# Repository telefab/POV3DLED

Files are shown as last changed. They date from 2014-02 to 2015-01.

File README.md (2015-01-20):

POV3DLED - Rotating LED globe
========

* The "Globe" directory contains an Arduino library to control the globe.
Examples are also provided. Code is also provided to manage a communication
between the globe and an external Arduino, by modulating the ground wire that
powers the globe logic.

* The "Things" directory contains 3D models of parts of the globe.

* The "ImageConverter" directory contains a Java program to convert
images to be able to draw them on the globe.

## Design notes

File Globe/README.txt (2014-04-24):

This is a library to control a LED globe using low-level functions. It also defines a bus that can be used to communicate with the globe using its ground wire.

Examples are available to display the world, to display a runner trying to go faster than the globe, or to display text.

For bus communication, an example is available where the text and the color can be changed.

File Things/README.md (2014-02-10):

Things
=========

This directory contains 3D models. OpenSCAD is required to open scad files.

The models are:

* connection-base: the LED and light sensor to detect a reference angle.

* jack2stick: the connection between the jack (rotating contact) and the globe axis.

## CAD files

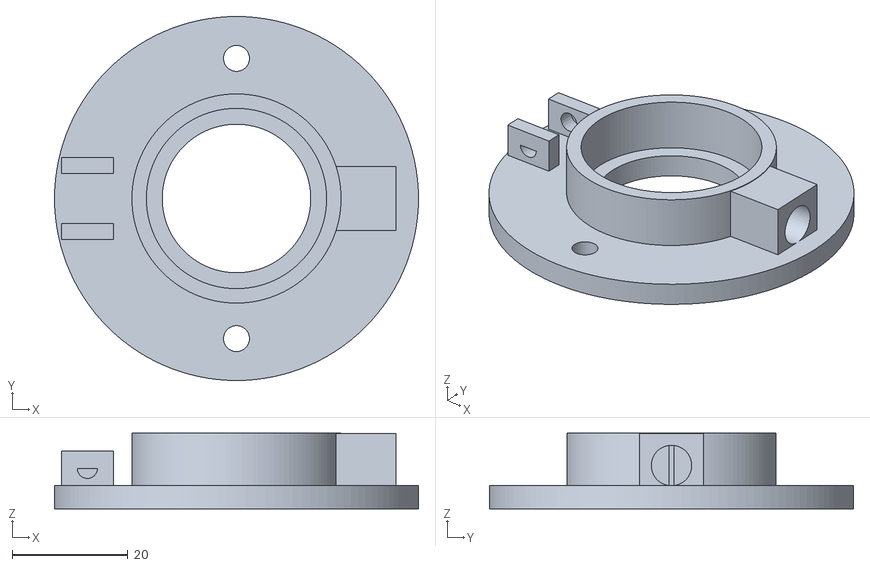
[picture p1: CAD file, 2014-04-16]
Things/base.stl
63.0 x 63.0 x 13.1

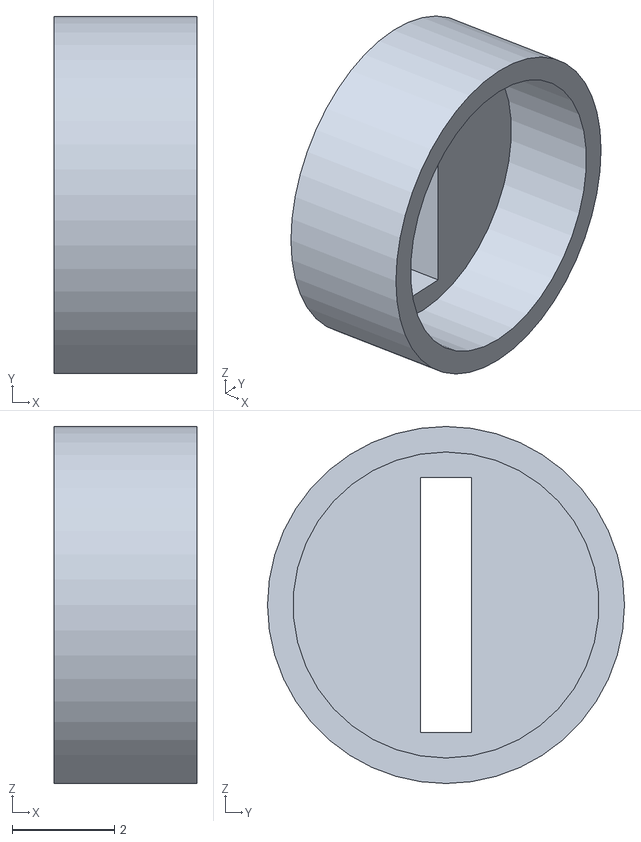
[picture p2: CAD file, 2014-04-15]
ThingsNew/led-cache.stl
2.80 x 7.00 x 7.00

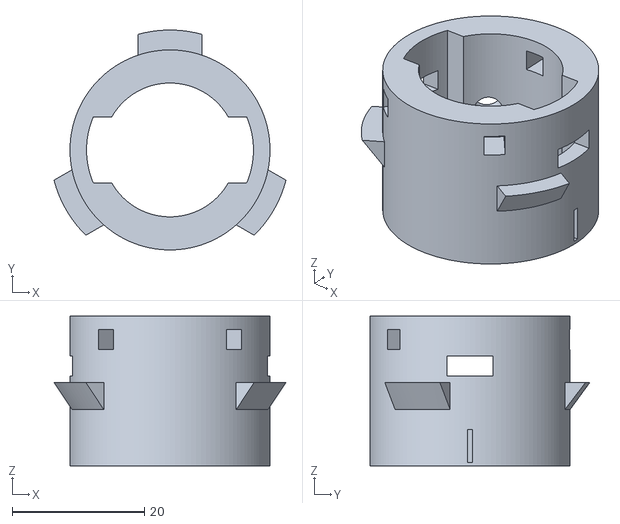
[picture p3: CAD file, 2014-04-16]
Things/cylinder.stl
35.0 x 33.2 x 22.6

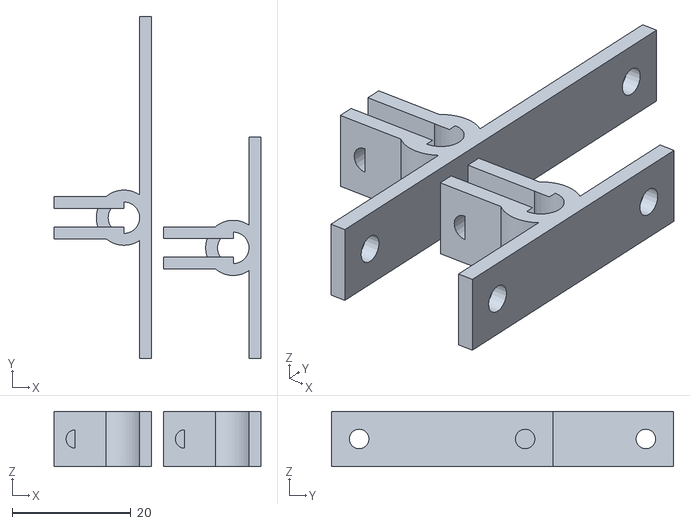
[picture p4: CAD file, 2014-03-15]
Things/arduino-holder.stl
34.8 x 57.6 x 9.30

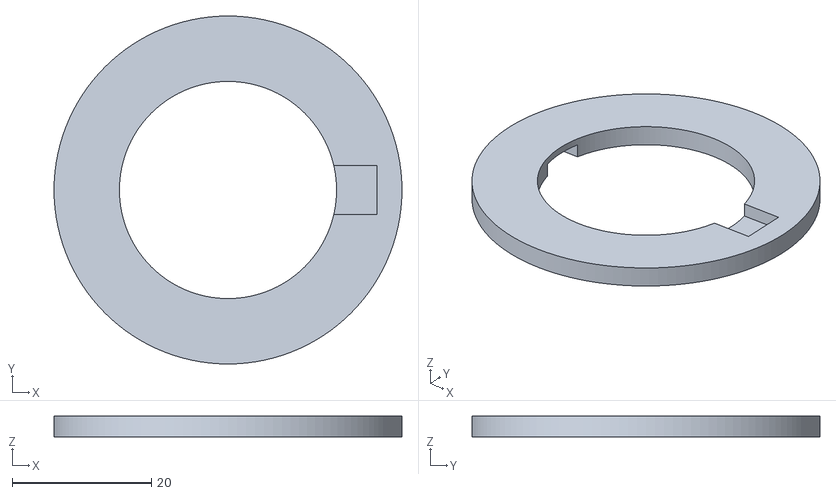
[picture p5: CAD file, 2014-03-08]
Things/spacer.stl
50.0 x 50.0 x 3.00

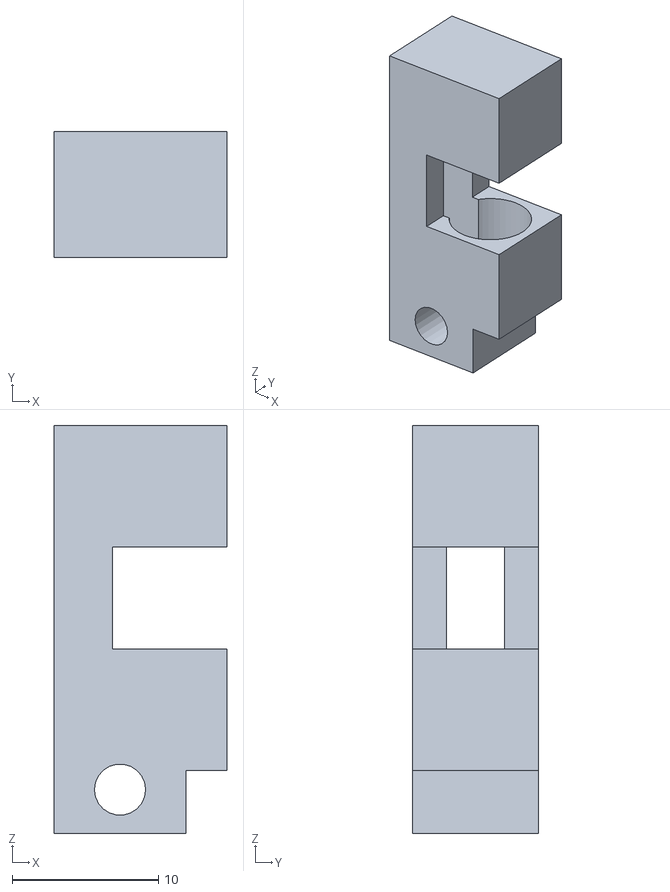
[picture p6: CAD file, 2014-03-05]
Things/connector.stl
11.8 x 8.60 x 27.9

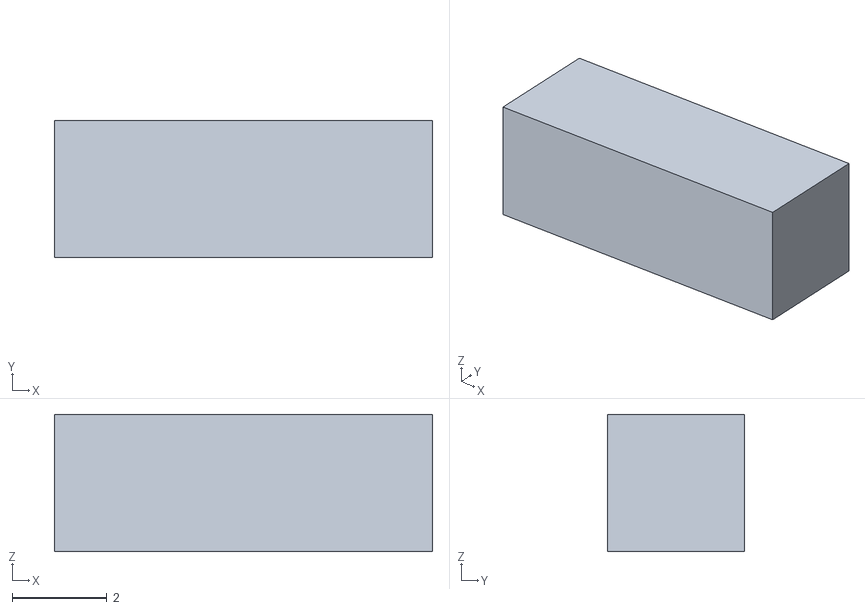
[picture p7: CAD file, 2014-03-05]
Things/block.stl
8.00 x 2.90 x 2.90

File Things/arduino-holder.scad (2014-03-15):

// Arduino support

// Resolution
$fa = 3; // Minimum angle (lower = higher max resolution, def 12)
$fs = 0.5; // Max fragment size (lower = higher min resolution, def 2)

// Measured parameters
holder_diam = 5.3;
hole_diam = 3.3;
dist_small = 27.94;
dist_large = 48.26;
screw_diam = 3.1;
center_offset = 5.08;

// Support parameters
depth = 2;
hole_space = 3;
screw_space = 2;
hole_size = (holder_diam + depth*2) / 3;

// Generic support
module support(dist, offset) {
	difference() {
		union() {
			// Base
			cube([hole_diam + hole_space * 2, dist + hole_diam + hole_space * 2, depth]);
			// Holder holder
			translate([0, dist/2 + hole_diam/2 + hole_space + offset, holder_diam/2 + depth])
				rotate([0, 90, 0])
					cylinder(r = holder_diam/2 + depth, h = hole_diam + hole_space * 2);
			// Holder screw support
			translate([0, dist/2 + hole_diam/2 + hole_space + offset - (hole_size + depth*2)/2, holder_diam/2 + depth])
				cube([hole_diam + hole_space * 2, hole_size + depth * 2, holder_diam/2 + depth + screw_diam + screw_space*2]);
		}
		// Holder space
		translate([0, dist/2 + hole_diam/2 + hole_space + offset, holder_diam/2 + depth])
			rotate([0, 90, 0])
				cylinder(r = holder_diam/2, h = hole_diam + hole_space * 2);
		// Holder screw support hole
		translate([0, dist/2 + hole_diam/2 + hole_space + offset - (hole_size + depth*2)/2 + depth, holder_diam/2 + depth])
			cube([hole_diam + hole_space * 2, hole_size, holder_diam/2 + depth + screw_diam + screw_space*2]);	
		// Holder screw space
		translate([hole_diam/2 + hole_space, dist/2 + hole_diam/2 + hole_space + offset - (hole_size + depth*2)/2, 2* depth + holder_diam + screw_space + screw_diam / 2])
			rotate([-90, 0, 0])
				cylinder(r = screw_diam/2, h = hole_size + depth * 2);
		// Arduino connection holes 
		translate([hole_space + hole_diam/2, hole_space + hole_diam/2, 0])
			cylinder(r = hole_diam/2, h = depth);
		translate([hole_space + hole_diam/2, hole_space + hole_diam/2 + dist, 0])
			cylinder(r = hole_diam/2, h = depth);
	}
}

// Small support
rotate([0, -90, 0]) 
	support(dist_small, 0);
// Big support
translate([-holder_diam - screw_diam - screw_space * 2 - depth*3, 0, 0])
	rotate([0, -90, 0]) 
		support(dist_large, -center_offset);

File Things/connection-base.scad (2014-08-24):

// Connection base
// This file contains separate elements:
// * a static base, fixed to the motor;
// * a rotating cylinder, fixed to the sphere.
// * a connector 
// It is used to transmit power between the base and the cylinder,
// and to add a LED and light sensor to detect a reference angle.

// Resolution
$fa = 3; // Minimum angle (lower = higher max resolution, def 12)
$fs = 0.5; // Max fragment size (lower = higher min resolution, def 2)

// Wire
wire_diam = 1.8;
// Motor base
base_diam = 63;
base_height = 4.0;
// Base screw
base_screw_diam = 4.5;
base_screw_sep = 48.5;
// Base hole
base_hole_height = base_height;
base_hole_diam = 25.7;
// Rotating cylinder
cyl_offset = base_height + 1;
cyl_in_diam = 20.2;
cyl_width = 2.5;
cyl_wire_width = 2.5;
cyl_wire_space = 10;
// Rotating screw
cyl_screw_offset = 13.3;
cyl_screw_diam = 4.1;
// light sensor
sensor_offset = 0.5;
sensor_diam = 5;
sensor_opening_width = 0.8;
// LED box
led_length = 12;
led_diam = 7;
led_box_width = 2;
led_opening_width = sensor_opening_width;
// LED cache
cache_width = 2.5;
cache_height = cyl_screw_offset - 0.2;
cache_diam = cyl_in_diam + (cyl_width + cyl_wire_width)*2 + 1;
// Conductor
conductor_diam_in = 31;
conductor_diam_out = 50;
conductor_height = 1;
conductor_sup_height = cyl_screw_diam;
conductor_sup_width = 10;
conductor_space = 3;
conductor_wire_space = 7;
conductor_wire_sep = 1;
conductor_offset = cyl_screw_offset + cyl_screw_diam + 0.2;
conductor_block_width = 3;
// Connector
connector_sup_offset = 1.3;
connector_sup_width = 4;
connector_base_depth = 2.8;
connector_base_width = 9;
connector_base_height = 6;
connector_base_hole_diam = 3.5;
connector_contact_diam = 7;
connector_contact_height = 7.5;
connector_contact_sep = 1;
connector_contact_wall = 0.8;
connector_sup_length = connector_contact_diam + connector_contact_wall*2;
connector_wire_space = 4;
// Cylinder height
cyl_height = conductor_offset + conductor_height * 2 + conductor_space + conductor_block_width + 2 - cyl_offset;

// Non-moving part
module base() {
	difference() {
		union() {
			difference() {
				union() {
					difference() {
						// Base
						cylinder(h = base_height, r = base_diam/2);
						// Bottom hole
						cylinder(h = base_hole_height, r = base_hole_diam/2);
						
					}
					// LED circular cache
					difference() {
						// Cylinder
						cylinder(h = cache_height, r = cache_diam/2 + cache_width);
						// Inside diameter
						cylinder(h = cyl_height, r = cache_diam/2);
					}
					// LED box
					translate([cache_diam/2, - led_diam/2 - led_box_width, 0]) {
						cube([led_length, led_diam + 2 * led_box_width, led_diam + led_box_width + base_height]);
					}
				}
				// LED space
				translate([cache_diam/2, 0, led_diam/2 + base_height])
					rotate([0, 90, 0])
						cylinder(h = led_length+1, r = led_diam/2);
				translate([cache_diam/2 - 2, -led_opening_width/2, base_height])
					cube([cache_width+4, led_opening_width, led_diam]);
			}
			// Holding part for the connector
			difference() {
				translate([-conductor_diam_out/2 - connector_sup_width - connector_sup_offset, -connector_sup_length/2 - connector_base_depth, 0])
					cube([connector_base_width, connector_sup_length + connector_base_depth*2, connector_base_height + base_height]);
				translate([-conductor_diam_out/2 - connector_sup_width - connector_sup_offset, -connector_sup_length/2, 0])
					cube([connector_base_width, connector_sup_length, connector_base_height + base_height]);
				translate([-conductor_diam_out/2 - connector_sup_offset - connector_sup_width + connector_base_width/2, connector_sup_length/2 + connector_base_depth, base_height + connector_base_height/2])
					rotate([90, 0, 0])
						cylinder(h = connector_sup_length + connector_base_depth*2, r = connector_base_hole_diam/2);
			}
		}
		// Screws
		translate([0,base_screw_sep/2,0])
			cylinder(h = cache_height, r = base_screw_diam/2);
		translate([0,-base_screw_sep/2,0])
			cylinder(h = cache_height, r = base_screw_diam/2);
	}
}

// Rotating part
module cyl() {
	translate([0, 0, cyl_offset]) {
		union() {
			difference() {
				// Cylinder
				cylinder(h = cyl_height, r = cyl_in_diam/2 + cyl_width + cyl_wire_width);
				// Inside diameter
				cylinder(h = cyl_height, r = cyl_in_diam/2);
				// Wire space
				intersection() {
					cylinder(h = cyl_height, r = cyl_in_diam/2 + cyl_wire_width);
					translate([-cyl_in_diam/2-(cyl_width+cyl_wire_width), -cyl_wire_space/2, 0])
						cube([cyl_in_diam+2*(cyl_width+cyl_wire_width), cyl_wire_space, cyl_height]);
				}
				// Screw
				translate([0, 0, cyl_screw_offset + cyl_screw_diam/2 - cyl_offset])
					rotate([0, 90, 130])
						cylinder(h = cyl_in_diam/2+cyl_width+cyl_wire_width, r = cyl_screw_diam/2);
				// Light sensor
				translate([cyl_in_diam/2 + cyl_wire_width - 1, 0, sensor_offset + sensor_diam/2])
					rotate([0, 90, 0])
						cylinder(h = cyl_width, r=sensor_diam/2);
				translate([cyl_in_diam/2 + cyl_wire_width - 1, -sensor_opening_width/2, sensor_offset])
					cube([cyl_width+4, sensor_opening_width, sensor_diam]);
				// Holes to connect the conductors
				translate([-cyl_in_diam/2-(cyl_width+cyl_wire_width), -conductor_wire_space/2, conductor_offset - cyl_offset + conductor_height])
					cube([cyl_in_diam+2*(cyl_width+cyl_wire_width), conductor_wire_space, conductor_space]);
				// Holes to block the top conductor
				rotate([0,0,50])
					translate([-cyl_in_diam/2-(cyl_width+cyl_wire_width), -conductor_block_width/2, conductor_offset - cyl_offset + 2*conductor_height + conductor_space])
						cube([cyl_in_diam/2+(cyl_width+cyl_wire_width), conductor_block_width, conductor_block_width]);
				rotate([0,0,130])
					translate([-cyl_in_diam/2-(cyl_width+cyl_wire_width), -conductor_block_width/2, conductor_offset - cyl_offset + 2*conductor_height + conductor_space])
						cube([cyl_in_diam/2+(cyl_width+cyl_wire_width), conductor_block_width, conductor_block_width]);
				rotate([0,0,270])
					translate([-cyl_in_diam/2-(cyl_width+cyl_wire_width), -conductor_block_width/2, conductor_offset - cyl_offset + 2*conductor_height + conductor_space])
						cube([cyl_in_diam/2+(cyl_width+cyl_wire_width), conductor_block_width, conductor_block_width]);
				
			}
			// Conductor support
			intersection() {
				translate([0, 0, conductor_offset - cyl_offset - conductor_sup_height]) {
					difference() {
						cylinder(h = conductor_sup_height, r1 = cyl_in_diam/2 + cyl_width + cyl_wire_width, r2 = cache_diam/2 + cache_width);
						cylinder(h = conductor_sup_height, r1 = cyl_in_diam/2 + cyl_wire_width, r2 = cyl_in_diam/2 + cyl_width + cyl_wire_width);
					}
				}
				union() {
					rotate([0, 0, 0])
						translate([-conductor_sup_width/2+0.2, 0, 0])
							cube([conductor_sup_width-0.4, cyl_in_diam + 2*(cyl_width + cyl_wire_width), conductor_offset - cyl_offset]);
					rotate([0, 0, 120])
						translate([-conductor_sup_width/2+0.2, 0, 0])
							cube([conductor_sup_width-0.4, cyl_in_diam + 2*(cyl_width + cyl_wire_width), conductor_offset - cyl_offset]);
					rotate([0, 0, 240])
						translate([-conductor_sup_width/2+0.2, 0, 0])
							cube([conductor_sup_width-0.4, cyl_in_diam + 2*(cyl_width + cyl_wire_width), conductor_offset - cyl_offset]);
				}
			}
		}
	}
}
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

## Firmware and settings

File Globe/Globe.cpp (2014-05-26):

#if defined(__AVR_ATmega2560__)

#include "Globe.h"
#include <avr/interrupt.h>

#define START_TIMER3 TCCR3B |= (1 << WGM12) | (1 << CS10)
#define STOP_TIMER3 TCCR3B &= ~((1 << WGM12) | (1 << CS10))

Globe* Globe::singleton = 0;

const PIN_TYPE Globe::ledPins[GLOBE_LEDS] = {PIN_F(2), PIN_F(3), PIN_F(4), PIN_F(5), PIN_F(6), PIN_F(7), PIN_K(0), PIN_K(1), PIN_K(2), PIN_B(1), PIN_B(0),
  PIN_B(3), PIN_B(2), PIN_L(1), PIN_K(3), PIN_L(3), PIN_L(2), PIN_L(5), PIN_L(4), PIN_L(7), PIN_L(6), PIN_G(1), PIN_G(0), PIN_D(7), PIN_G(2), 
  PIN_C(1), PIN_C(0), PIN_C(3), PIN_C(2), PIN_C(5), PIN_C(4), PIN_C(7), PIN_C(6), PIN_A(6), PIN_A(7), PIN_A(4), PIN_A(5), PIN_A(2), PIN_A(3)};

const PIN_TYPE Globe::colorPins[GLOBE_COLORS] = {PIN_A(0), PIN_F(0), PIN_A(1)};

const PIN_TYPE Globe::sensorPin = PIN_E(4);

Globe::Globe() :
  columnCur(GLOBE_COLUMNS-1),
  ledCur(GLOBE_LEDS-1),
  columnNxt(0),
  ledNxt(0),
  columnRotNxt(0),
  roundCount(0),
  roundDelay(0),
  paused(1),
  remRounds(0)
{
  uint8_t i, j;
  // Set the globe buffer to all black
  for (i = 0; i < GLOBE_COLUMNS; i++)
    for (j = 0; j < GLOBE_LEDS; j++)
      imageBuffer[i][j] = 0;
}

Globe* Globe::get() {
  if (!Globe::singleton)
    Globe::singleton = new Globe();
  return Globe::singleton;
}

void Globe::begin() {
  uint8_t i;
  // LED controls are outputs
  for (i = 0; i < GLOBE_LEDS; i++)
    ledPins[i].makeOutput(1);
  for (i = 0; i < GLOBE_COLORS; i++)
    colorPins[i].makeOutput(1);
  // Round sensor is an input with a pull-up resistor
  sensorPin.makeOutput(0);
  //sensorPin.set(1);
  // Disable global interrupts
  cli();
  // Initialize the round timer (Timer1, /256, counting, compare interrupt at max to detect globe stop)
  TCCR1A = 0;
  TCCR1B = 0;
  TCCR1B |= (1 << CS12);
  TIMSK1 |= (1 << OCIE1A);
  OCR1A = 0xFFFF;
  // Initialize the LED timer (Timer3, /1, compare interrupt, not started yet)
  TCCR3A = 0;
  TCCR3B = 0;
  TIMSK3 |= (1 << OCIE1A);
  // Activate round sensor interrupts (INT4, rising)
  EIMSK |= (1 << INT4);
  EICRB |= (1 << ISC41) | (1 << ISC40); 
  // enable global interrupts
  sei();
}

void Globe::_restartRound() {
  // Restart the display
  // Keep the rotation, to do before resetting anything
  columnRotNxt = getRotation();
  columnNxt = 0;
  ledNxt = 0;
  paused = 0;
  // Decrease the rounds delay if any
  if (remRounds > 0)
    remRounds--;
}

uint8_t Globe::_displayLedNxt() {
  uint8_t i;
  // Switch the previous led off
  ledPins[ledCur].set(0);
  // Pause after switching the LED off if done
  if (paused)
    return 0;
  // Select the right colors
  for (i = 0; i < GLOBE_COLORS; i++)
    colorPins[i].set(((~imageBuffer[columnRotNxt][ledNxt]) >> i) & 1);
  // Switch the proper led on
  ledPins[ledNxt].set(1);
  // Save the new state
  columnCur = columnNxt;
  ledCur = ledNxt;
  // Select the next LED to display
  ledNxt = ledCur + 1;
  columnNxt = columnCur;
  if (ledNxt >= GLOBE_LEDS) {
    ledNxt = 0;
    columnNxt+= 1;
    if (columnNxt >= GLOBE_COLUMNS) {
      columnNxt = 0;
      // Finished the round, pause
      paused = 1;
    }
    // Precompute the rotated column to display
    columnRotNxt+= 1;
    if (columnRotNxt >= GLOBE_COLUMNS)
      columnRotNxt = 0;
  }
  return 1;
}

uint8_t Globe::_isFirstRound() {
  return roundCount == 0;
}

uint8_t Globe::_isAccelRound() {
  // The 20 first rounds are the acceleration phase
  return roundCount < 20;
}

void Globe::_clearRound() {
  roundCount = 0;
  roundDelay = 0;
}

void Globe::_setRoundDelay(uint16_t delay) {
  roundDelay = delay;
  // Count the first rounds
  if (roundCount < 255)
    roundCount++;
}

uint16_t Globe::getRoundDelay() {
  return roundDelay;
}

uint8_t Globe::getWidth() {
  return GLOBE_COLUMNS;
}

uint8_t Globe::getHeight() {
  return GLOBE_LEDS;
}

void Globe::setLed(uint8_t column, uint8_t line, uint8_t color) {
  imageBuffer[column][line] = color;
}

uint8_t Globe::getLed(uint8_t column, uint8_t line) {
  return imageBuffer[column][line];
}

void Globe::setLedRot(uint8_t column, uint8_t line, uint8_t color) {
  uint8_t columnRot = column + getRotation();
  if (columnRot >= GLOBE_COLUMNS)
    columnRot-= GLOBE_COLUMNS;
  imageBuffer[columnRot][line] = color;
}

uint8_t Globe::getLedRot(uint8_t column, uint8_t line) {
  uint8_t columnRot = column + getRotation();
  if (columnRot >= GLOBE_COLUMNS)
    columnRot-= GLOBE_COLUMNS;
  return imageBuffer[columnRot][line];
}

void Globe::rotate(int16_t steps) {
  // The rotated column must stay in the buffer width
  if (steps > columnRotNxt)
    columnRotNxt-= steps - GLOBE_COLUMNS;
  else {
    columnRotNxt-= steps;
    if (columnRotNxt >= GLOBE_COLUMNS)
      columnRotNxt-= GLOBE_COLUMNS;
  }
}

void Globe::clearRotation() {
  // Displayed column is the actual column
  columnRotNxt = columnNxt;
}

uint8_t Globe::getRotation() {
  if (columnRotNxt >= columnNxt)
    return columnRotNxt - columnNxt;
  else
    return GLOBE_COLUMNS - columnNxt + columnRotNxt;
}

void Globe::delayRound(uint16_t rounds) {
  // Actively wait for the rounds to get to 0
  remRounds = rounds;
  while (remRounds > 0) {}
}

uint8_t Globe::passedRound(uint16_t rounds) {
  if (remRounds == 0) {
    // Start again once rounds have passed
    remRounds = rounds;
    return 1;
  }
  return 0;
}

/**
 * Called at each round by
 * the round sensor to synchronize the display
 */
ISR (INT4_vect)
{
  Globe* globe = Globe::get();
  uint16_t delay = TCNT1;
  // Do not accept rounds faster than 80% of the last delay
  // Except during the first acceleration phase
  if (globe->_isAccelRound() || delay >= (int) (8. * ((float) globe->getRoundDelay()) / 10.)) {
    // Set the measured delay as LED timer delay and reset
    // The 64 factor is due to the different timer speeds
    // The -1 is an adjustment parameter
    // to make sure that everything is displayed
    OCR3A = (int) (((float) delay) / (((float) (GLOBE_LEDS * GLOBE_COLUMNS)) / 256.));
    TCNT1 = 0;
    // Start the round again
    // not at first round because the speed of the globe is unknown
    if (!globe->_isFirstRound()) {
      globe->_restartRound();
      START_TIMER3;
    }
    globe->_setRoundDelay(delay);
  }
}

/**
 * Called by the first timer if a round is too slow
 */
ISR(TIMER1_COMPA_vect) {
  Globe::get()->_clearRound();
}

/**
 * Called by a timer once for each LED to display,
 * at a variable speed depending on the round sensor
 */
ISR(TIMER3_COMPA_vect) {
  if (!Globe::get()->_displayLedNxt()) {
    // Stop the timer if paused
    STOP_TIMER3;
    TCNT3 = 0;
  }
}

#endif

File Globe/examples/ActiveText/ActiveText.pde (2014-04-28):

/**
 * Display some text rotating on the globe.
 * There is a text by default, and it can be changed by sending text through the bus.
 * To change the color, send #3, where 3 is replaced by the number of the wanted color.
 */

#define CHAR_WIDTH 5
#define CHAR_SPACE 1
#define CHAR_FULL_WIDTH (CHAR_WIDTH+CHAR_SPACE)
#define CHAR_HEIGHT 5

/**
 * Synchronize these settings between master and slave
 */
#define MAX_LENGTH 25

#include <Globe.h>
#include <BusSlave.h>
#include <Pin.h>

/**
 * Change here the text to display
 */
char text[MAX_LENGTH] = "Telecom Bretagne";
/**
 * Change here the color of the text
 * It is a bit mask with 3 bits Red, Greed, and Blue
 */
uint8_t textColor = 1;

/**
 * Text received through the bus
 */
char receivedText[MAX_LENGTH];

/**
 * Space, then letters from A to Z.
 * Each letter is 5x5 pixels
 */
const byte letters[27][5] = {
  {0x00,0x00,0x00,0x00,0x00},
  {0x7c,0x44,0x44,0x7c,0x44},    
  {0x7c,0x44,0x78,0x44,0x7c},  
  {0x7c,0x40,0x40,0x40,0x7c},  
  {0x78,0x44,0x44,0x44,0x78},  
  {0x7c,0x40,0x78,0x40,0x7c},
  {0x7c,0x40,0x70,0x40,0x40},
  {0x7c,0x40,0x4c,0x44,0x7c},
  {0x44,0x44,0x7c,0x44,0x44},
  {0x7c,0x10,0x10,0x10,0x7c},
  {0x0c,0x04,0x04,0x44,0x7c},
  {0x44,0x48,0x70,0x48,0x44},
  {0x40,0x40,0x40,0x40,0x7c},
  {0x44,0x6c,0x54,0x44,0x44},
  {0x44,0x64,0x54,0x4c,0x44},
  {0x38,0x44,0x44,0x44,0x38},  
  {0x78,0x44,0x78,0x40,0x40},              
  {0x7c,0x44,0x44,0x7c,0x10},            
  {0x78,0x44,0x78,0x44,0x44},            
  {0x7c,0x40,0x7c,0x04,0x7c},            
  {0x7c,0x10,0x10,0x10,0x10},              
  {0x44,0x44,0x44,0x44,0x7c},            
  {0x44,0x44,0x28,0x28,0x10},            
  {0x44,0x44,0x54,0x54,0x28},            
  {0x44,0x28,0x10,0x28,0x44},            
  {0x44,0x44,0x28,0x10,0x10},            
  {0x7c,0x08,0x10,0x20,0x7c}
};

Globe *globe = Globe::get();
BusSlave *bus = BusSlave::get();

unsigned int textLength = strlen(text);
const unsigned int globeWidth = globe->getWidth();
const unsigned int heightOffset = (globe->getHeight() - CHAR_HEIGHT)/2;

uint8_t i, currentPos, currentIndex, currentCol, endFrom;

void setup() {
  currentPos = 0;
  currentCol = 0;
  endFrom = 0;
  globe->begin();
  bus->begin();
}

void loop() {
  // Update the display, only once per globe round
  if (globe->passedRound()) {
    // Always keep the last columns clear to separate start and end of text
    for (i = 0; i < CHAR_HEIGHT; i++) {
      globe->setLedRot(0, i+heightOffset, 0);
    }
    // If the text is not fully displayed
    if (endFrom == 0) {
      if (currentCol == 0) {
        // Select the index of the character in the letter array
        currentIndex = text[currentPos];
        if (currentIndex >= 65 && currentIndex <= 90)
          currentIndex-= 64;
        else if (currentIndex >= 97 && currentIndex <= 122)
          currentIndex-= 96;
        else
          currentIndex = 0;
      }
      // Display one column of text
      for (i = 0; i < CHAR_HEIGHT; i++) {
        globe->setLedRot(globeWidth-CHAR_FULL_WIDTH, i+heightOffset, ((letters[currentIndex][i] >> (CHAR_FULL_WIDTH-currentCol)) & 1) * textColor);
      }
      // Get ready for next column
      currentCol++;
      if (currentCol > CHAR_WIDTH) {
        currentCol = 0;
        currentPos++;
        if (currentPos > (textLength-1)) {
          currentPos = 0;
          endFrom = 1;
        }
      }
    } else {
      // Wait until the text has made a full round before displaying again
      if (endFrom >= globeWidth - CHAR_FULL_WIDTH)
        endFrom = 0;
      else
        endFrom++;
    }
    // Rotate
    globe->rotate(-1);
  }
  // Listen to the bus
  if (bus->readString(receivedText, MAX_LENGTH)) {
    if (receivedText[0] == '#' && strlen(receivedText) == 2) {
      // Change the text color
      textColor = receivedText[1] - 48;
    } else {
      // Change the text itself
      strcpy(text, receivedText);
      textLength = strlen(text);
      currentPos = 0;
      currentCol = 0;
      endFrom = 0;
      globe->rotate(-5);
    }
  }
}

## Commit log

2013-04-11 Create povled.ino
    Dans ce code:
    -On définit une matrice "matriceallumer" qui indique si la led est allumée et une matrice "matricecouleur" qui indique la couleur de la led.
    -On déclenche l'allumage en boucle des colonnes de cette matrice
    -Cette boucle revient à la première colonne dès que le capteur rencontre un obstacle.
2013-04-11 Create Cadre.java
    Contient la création des menus et de l'interface
2013-04-11 Create PanDessin.java
    Contient les fonctions de traitement d'image
2013-09-23 Added the connection base model (OpenSCAD)
    The connection base is used to connect the rotating Arduino to the
    outside power. It also contains a LED and light sensor to locate the
    rotation reference angle.
    [connection-base.scad]
2013-09-29 Proposal of new LED controller software
    Should make the globe brighter and more precise.
    Not tested yet, TODO.
2013-09-29 Fixed a risk of burning LEDs
    LEDs should never be on more than half of the time at a high frequency
    to avoid burning them. The voltage is higher than the LEDs support in a
    static situation.
    The setup test was wrong.
2013-10-02 This works better (by LED)
    Still slower than the basic version, but non blocking and adjustable.
2013-10-11 Now use solid supports instead of wires
    [connection-base.scad]
2014-02-01 3D part for Audio Jack and central Stick
    [piece_jack2stick.STL]
2014-02-04 New low-level library to control the globe
    Tested and working!
    Uses AVR functions instead of Arduino functions for timing and PIN
    control.
    This is much much faster.
2014-02-05 Fixed a ghost column bug
    There was a capacity overflow on the image buffer.
    Plus: the image is initialized to all black.
    [Globe.cpp]
2014-02-05 Fixed a synchronization bug
    The difference between the two timers is a factor of 4, not 8.
    [Globe.cpp]
2014-02-06 Accuracy improvements and cleaning up
    Made sure LEDs are on only when their location is accurate:
    * do not switch LEDs on before one full round has been detected, to
    know the globe speed
    * switch all LEDs off once a round is finished until a new round is
    detected, do not start the next round immediately
    Cleaned up the indentation.
2014-02-07 Added convenient utilities to the library
    Rotation can now be done effortlessly thanks to an offset built-in the
    LED refreshing mechanism.
    It is now possible to wait actively during a set number of rounds.
2014-02-07 Fixes and optimizations
    Fixed the previous non-working commit.
    Tried to optimize the speed: the modulo seemed to be very slow.
    Not tested, I would recommend using the version 2 commits ago because
    it is tested and working.
    [Globe.cpp]
2014-02-08 Speed optimization
    The LED switching has to be very fast.
2014-02-09 Revert "Speed optimization"
    This reverts commit 36e4cf8e200deb151b597c6cdc8c26749f9d53e2.
    [Globe.cpp]
2014-02-09 Tiny optimizations
    Added again the simple optimizations, without the pin management change
2014-02-09 Important fixes
    Rotation works now, the globe displayed nothing due to an error on pin
    setting.
    [Globe.cpp, Runner.pde]
2014-02-09 Fixed the text example
    Now tested and working
    [Text.pde]
2014-02-10 Removed the rotating connection from connection-base
    The connection is now due to a Jack plug. The base is still useful for
    the round sensor.
    [connection-base.scad]
2014-02-10 Cleaned up
    Remove useless files, organized into directories, added some comments.
    [base.stl, connection-base.scad, connection-base.stl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]
2014-02-10 Removed useless file
    [connection-base.stl]
2014-03-05 Trying a new circular connector with springers.
    [base.stl, block.stl, connection-base.scad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]
2014-03-05 Fixed the screw hole for the connector
    [base.stl, connection-base.scad, connector.stl]
2014-03-08 Made the conductor connection safer
    Separated the 2 connectors by plastic.
    [connection-base.scad, cylinder.stl, spacer.stl]
2014-03-15 Added a holder for the Arduino
    Connection between the Arduino and the axis of the globe.
    [arduino-holder.scad, arduino-holder.stl]
2014-03-23 Increased the accuracy and avoided sync losses
    The timer managing the LEDs one by one is now 64 times faster,
    increasing the accuracy. Plus delay computation is done in float.
    To ignore fake sync interrupts, rounds that are too fast compared to
    the previous one are ignored, except during the initial acceleration
    phase.
    [Globe.cpp]
2014-04-15 Added a cache to focus the LED
    Made to avoid synchronization issues.
    [connection-base.scad, led-cache.stl]
2014-04-15 Weird uppercase issue
    [arduino-holder.scad, arduino-holder.stl, base.stl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]
2014-04-15 Fix for the weird issue
    [arduino-holder.scad, arduino-holder.stl, base.stl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]
2014-04-16 Made the light more focused for synchronization
    [base.stl, connection-base.scad, cylinder.stl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]
2014-04-24 Added communication with the globe while rotating
    This is done by modulating the ground wire.
    The current version is not perfectly reliable, could be optimized, but
    works.
    [jack2stick.stl]
2014-04-27 Smarter error correction [to test]
    * Send data per bytes and check the size on reception
    * Parity bit for each byte
    * Byte redundancy to avoid losing data
    Removed the complex and heavy string redundancy mechanism.
    Not tested yet.
    [ActiveText.pde, ActiveTextSender.pde]
2014-05-09 Fixed some bugs on the snake
    Still not fully checked
    [Snake.pde, SnakeSender.pde]
2014-05-14 Snake fixed
    Checked and working on the sphere.
    [Snake.pde, SnakeSender.pde]
2014-05-26 Improved globe display synchronization
    Replaced the Pull-up by a pull-down.
    Now the sensor is always 0 except when in front of the LED.
    This is better to avoid noise (disconnects bring back to 0)
    [Globe.cpp]
2014-08-24 More visual base 3D OpenSCAD file
    All parts activated and located where they should be
    [connection-base.scad]
2015-01-21 On arrete les tests
